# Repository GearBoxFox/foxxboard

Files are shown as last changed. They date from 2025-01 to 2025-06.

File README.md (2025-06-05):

## Foxxboard: A Wireless, split ergonomic keyboard for normal keyboard users
---
This keyboard was inspired by the Lily85 keyboard layout, keeping a more standard 64 key layout while also gaining the bonus ergonomics of a split keyboard. I designed it to be a multi purpose keyboard, ergonomic for typing while still having access to all the needed keys for competitive gaming. I also decided to build it wirelessly so I can easily take and use it with my laptop on the go.

*insert final image here*

# Features
- 64 key layout
- 4 key thumb cluster per side
- BLE wireless support using nice!nano v2
- Traditional pinky row using 1.5u keys
- Low profile using Gateron ks33 switches 
- 2x nice!view for low powered HUD
- Custom firmware written in RMK using Rust :ferrisyippee: 

## > [!NOTE]
> The firmware for the display module is still a WIP, but I'm talking with the head RMK dev 
> to get it fully running. The firmware bundled with this has parts of a display demo, and my 
> hackpad has a working display in RMK.

# PCB

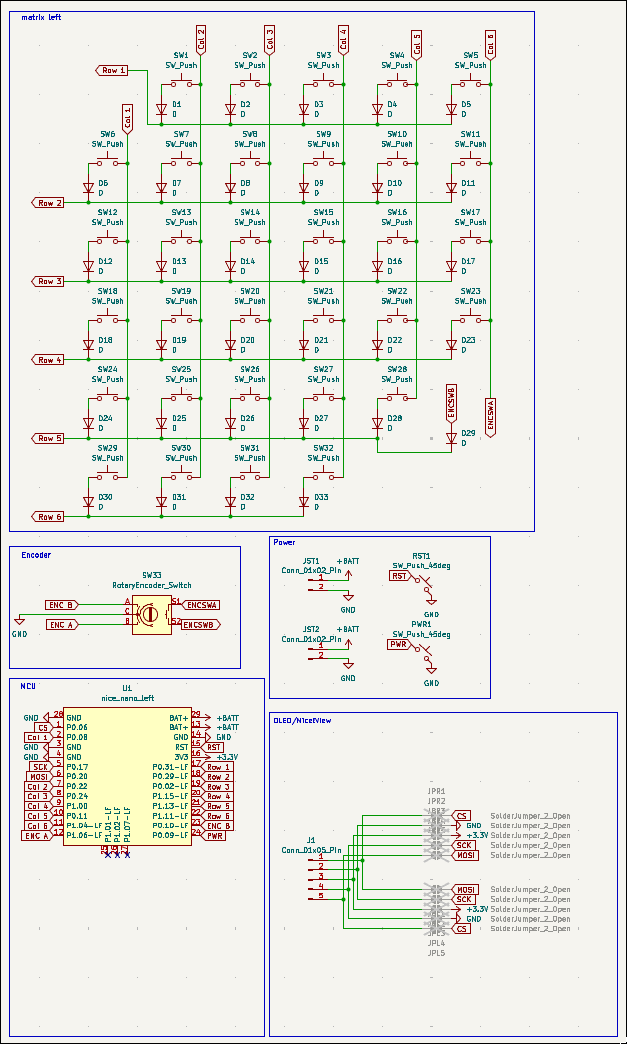
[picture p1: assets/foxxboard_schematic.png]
PCB Schematic

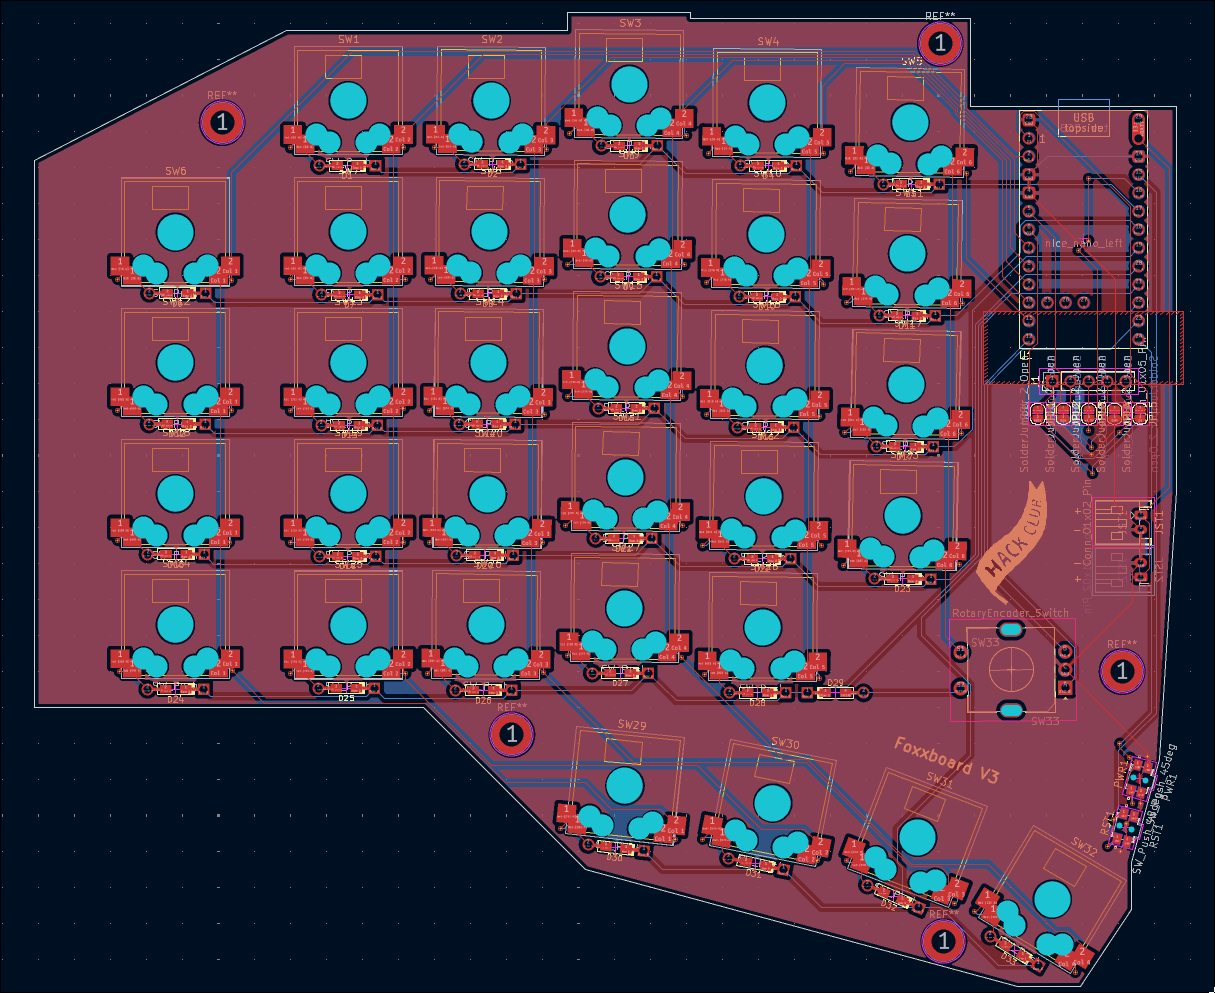
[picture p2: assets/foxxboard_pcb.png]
PCB

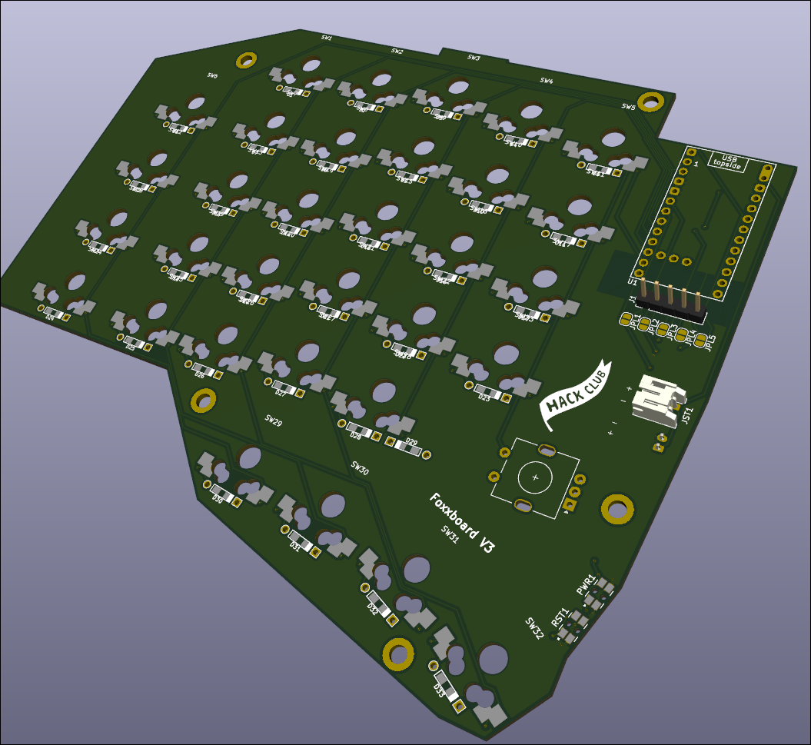
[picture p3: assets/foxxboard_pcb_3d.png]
PCB 3D


# Renders

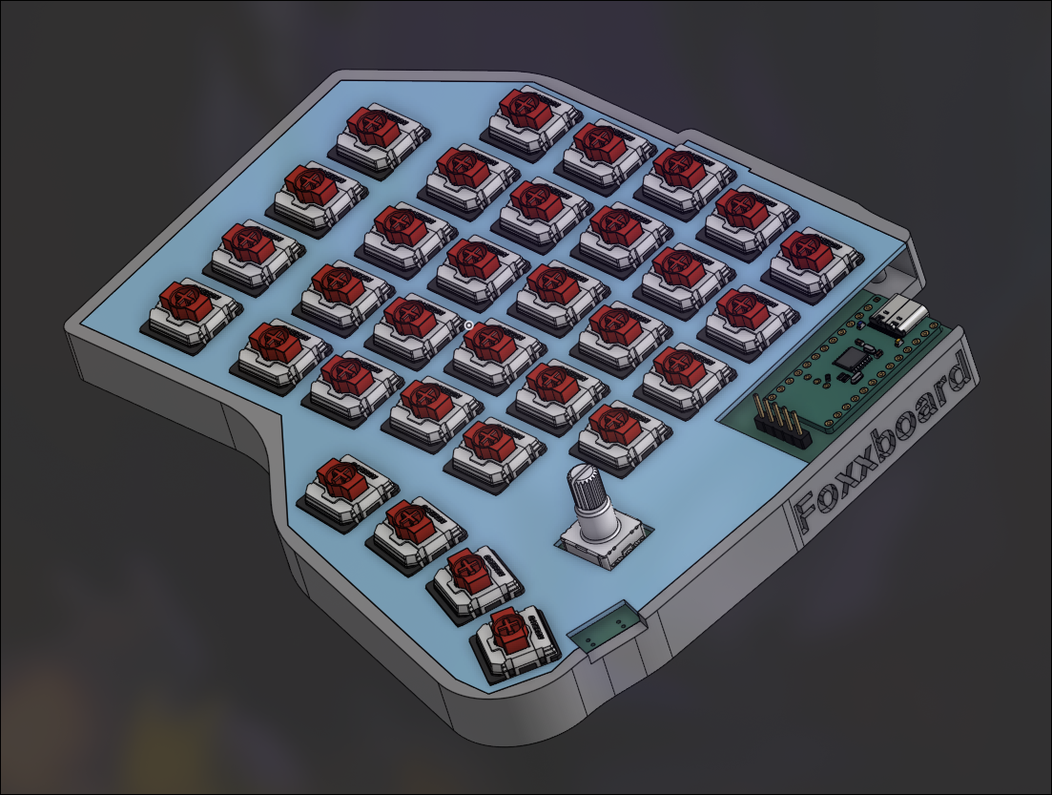
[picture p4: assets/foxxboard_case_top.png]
Top Case

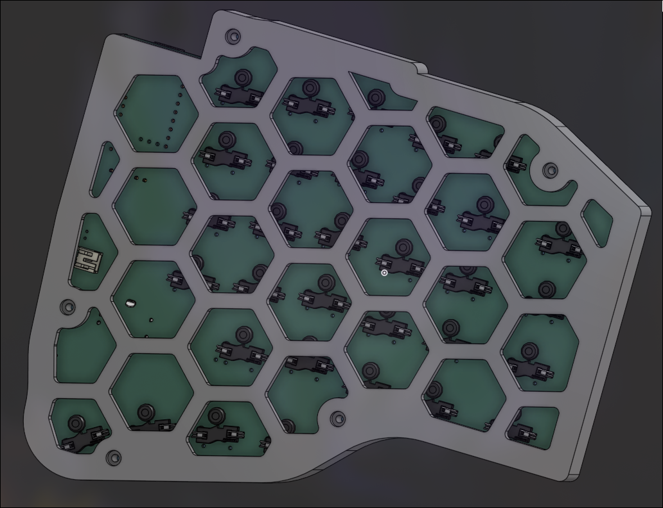
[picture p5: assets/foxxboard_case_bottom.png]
Bottom Case


# BOM 

## > [!NOTE]
> I plan on printing my own case.
>
> I also need to double check prices on things as there have almost certainly been price changes.

| Name | Qty | Price |
|---|-----|---|
| PCB | 5 | $14.59 w/shipping |
| GLP ks33 Banana | 64  | $21.48 w/shipping |
| THT 1N4148 Diodes | 64  | Hackclub |
| EC11 Encoder | 2 | $2.00 AliExpress  |
| Clone Nice!Nano V2 | 2 | $5.42 AliExpress  |
| GLP Hot-swap sockets | 100 | $8.42 AliExpress  |
| 0.91" OLED Display | 2 | $3.20 AliExpress  |
| 3.7v LiPo Battery | 2 | $6.00 |
| EVQ-P7C01P Switch | 2 | $0.56 Digikey |

| Supplier | Price (+ Shipping) | 
|---|---|
| JLCPCB | $14.59 |
| Keebio | $22.48 |
| AliExpress  | $20.20 |
| Typeractive | $10.90 |
| Total | $68.17 |

| Extras | Qty | Price |
|---|-----|---|
| Nice!View | 2 | $40 |
| True Nice!Nano V2 | 2 | $50 |

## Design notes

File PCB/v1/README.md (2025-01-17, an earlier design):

# hackpad-v2
Kicad, Ergogen, and QMK files for Hackclub's Hackpad V2

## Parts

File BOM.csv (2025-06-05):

Item | Cost | Amount | Total Cost | Link
PCB | $28.84 | 1 | $28.84 w/shipping
Gateron ks33 banana switches | $0.25 | 64 | $21.48 w/shipping | https://keeb.io/products/gateron-ks-33-low-profile-2-0-switches?variant=41274159628382
THT 1N4148 Diodes | Hackclub | 64 | HC
EC11 Encoder | self provide | 2 | self provide
Nice!Nano V2 | $25 (self provide) | 2 | $50 | https://typeractive.xyz/products/nice-nano
GLP sockets | $7.81 | 1 | $7.81 | https://www.aliexpress.us/item/3256806931242093.html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
3.7v LiPo | $4 (has to ship with nice!nano I might just buy myself as well idk) | 2 | $8 | https://typeractive.xyz/products/lithium-battery-110mah?variant=43294731665639
Total for HC | $58.13
Total for me | $58

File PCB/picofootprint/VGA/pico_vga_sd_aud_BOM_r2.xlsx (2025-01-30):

RPI-PVAS pico_vga_sd_aud BOM Rev2
17/079/2020
Reference designators | Quantity | Manufacturer Part Number (MPN) | Manufacturer | Description | Value
C1, C2 | 2 | GCM188R71C105KA64J | Murata | CAP CER 1UF 16V X7R 0603 | 1u
C9, C11 | 2 | GRM188R71A225KE15D | Murata | CAP CER 2.2UF 10V X7R 0603 | 2.2u
C3, C10, C16, C19 | 4 | GRM188R61A106KE69J | Murata | CAP CER 10UF 10V X5R 0603 | 10u
C4, C5, C6, C7, C8, C12, C13 | 7 | GRM155R71E104KE14J | Murata | CAP CER 0.1UF 25V X7R 0402 | 100n
C14, C15, C21 | 3 | GRM219R60J476ME44D | Murata | CAP CER 47UF 6.3V X5R 0805 | 47u
C17, C18 | 2 | GRM155R71H222KA01D | Murata | CAP CER 2200PF 50V X7R 0402 | 2.2n
D1 | 1 | MBR120VLSFT1G | ON Semiconductor | DIODE SCHOTTKY 20V 1A SOD123FL | MBR120VLSFT1G
J1, J2 | 2 | SJ-3523-SMT-TR | CUI Devices | CONN JACK STEREO 3.5MM SMD R/A | SJ-3523-SMT
J3 | 1 | 104031-0811 | Molex | CONN MICRO SD CARD PUSH-PULL R/A | 104031-0811
J4 | 1 | L77HDE15SD1CH4F | Amphenol ICC (Commercial Products) | CONN DSUB HD RCPT 15POS R/A SLDR | L77HDE15SD1CH4F
J5 | 1 | 10103594-0001LF | Amphenol ICC (FCI) | CONN RCPT USB2.0 MICRO B SMD R/A | 10103594-0001LF
J6 | 1 | TSW-102-23-T-S | Samtec Inc. | CONN HEADER VERT 2POS 2.54MM | TSW-102-23-T-S
J7 | 1 | 67997-208HLF | Amphenol ICC (FCI) | CONN HEADER VERT 8POS 2.54MM | 67997-208HLF
R1, R2 | 2 | RC0402FR-07220RL | Yageo | RES SMD 220 OHM 1% 1/16W 0402 | 220
R3, R4 | 2 | RC0402FR-07100RL | Yageo | RES SMD 100 OHM 1% 1/16W 0402 | 100
R5, R6 | 2 | RC0402FR-07470RP | Yageo | RES SMD 470 OHM 1% 1/16W 0402 | 470
R7, R8 | 2 | RC0402FR-071K8L | Yageo | RES SMD 1.8K OHM 1% 1/16W 0402 | 1.8K
R10, R11 | 2 | RC0402FR-0747RL | Yageo | RES SMD 47 OHM 1% 1/16W 0402 | 47
R20, R21, R22, R27, R32, R37 | 6 | RC0402FR-071KP | Yageo | RES SMD 1K OHM 1% 1/16W 0402 | 1k
R23, R24 | 2 | RC0402FR-0710KP | Yageo | RES SMD 10K OHM 1% 1/16W 0402 | 10k
R26, R31, R36 | 3 | RC0402FR-07499RL | Yageo | RES SMD 499 OHM 1% 1/16W 0402 | 499
R28, R33, R38 | 3 | RC0402FR-072KL | Yageo | RES SMD 2K OHM 1% 1/16W 0402 | 2k
R29, R34, R39 | 3 | RC0402FR-074K02L | Yageo | RES SMD 4.02K OHM 1% 1/16W 0402 | 4.02k
R30, R35, R40 | 3 | RC0402FR-078K06L | Yageo | RES SMD 8.06K OHM 1% 1/16W 0402 | 8.06k
SW1, SW2, SW3, SW4 | 4 | 434133025816 | Würth Elektronik | TACT SWITCH 4.2X3.2MM VERTICAL T | 434133025816
U1 | 1 | TLV70033DDCR | Texas Instruments | IC REG LINEAR 3.3V 200MA SOT23-5 | TLV70033DDCR
U3 | 1 | NC7WZ16P6X | ON Semiconductor | IC BUF NON-INVERT 5.5V SC70-6 | NC7WZ16P6X
U4 | 1 | PCM5101APWR | Texas Instruments | IC DAC 16/24/32BIT 384K 20TSSOP | PCM5101APWR

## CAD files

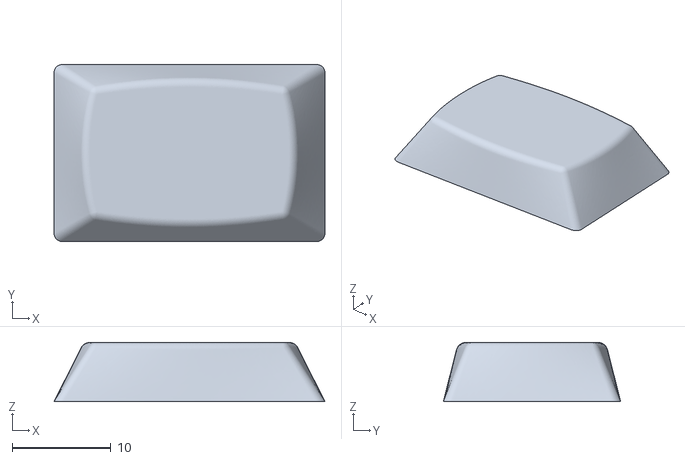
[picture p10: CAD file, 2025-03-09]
PCB/3d/AdhesionSupport_MFP_1.5u.step.stl
27.5 x 18.0 x 6.00

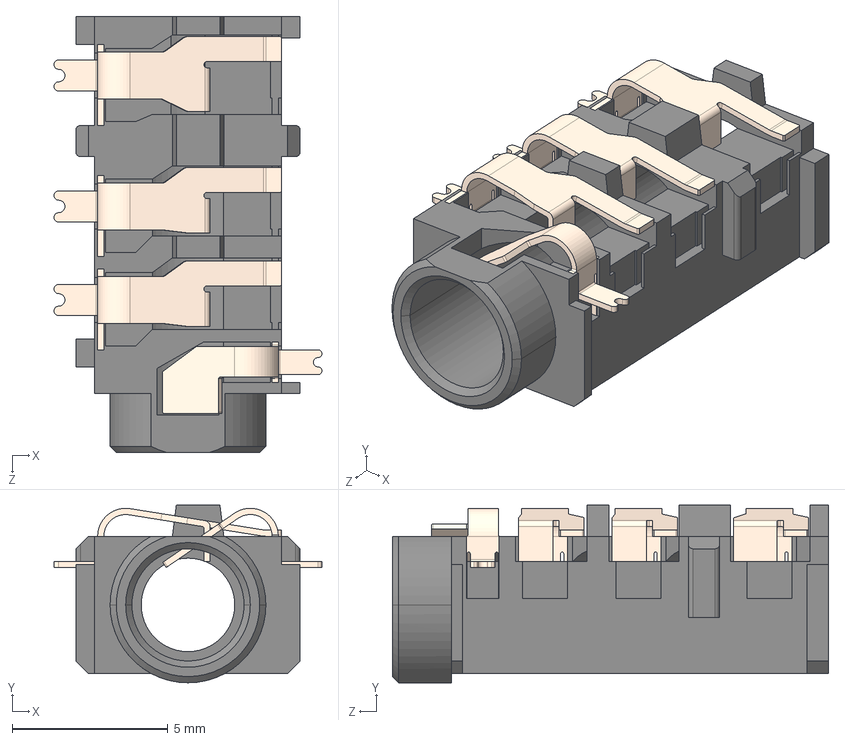
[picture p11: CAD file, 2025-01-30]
PCB/Keebio-Parts/3dmodels/CUI_SJ-43614-SMT-TR.step
8.60 x 5.70 x 14.0 mm

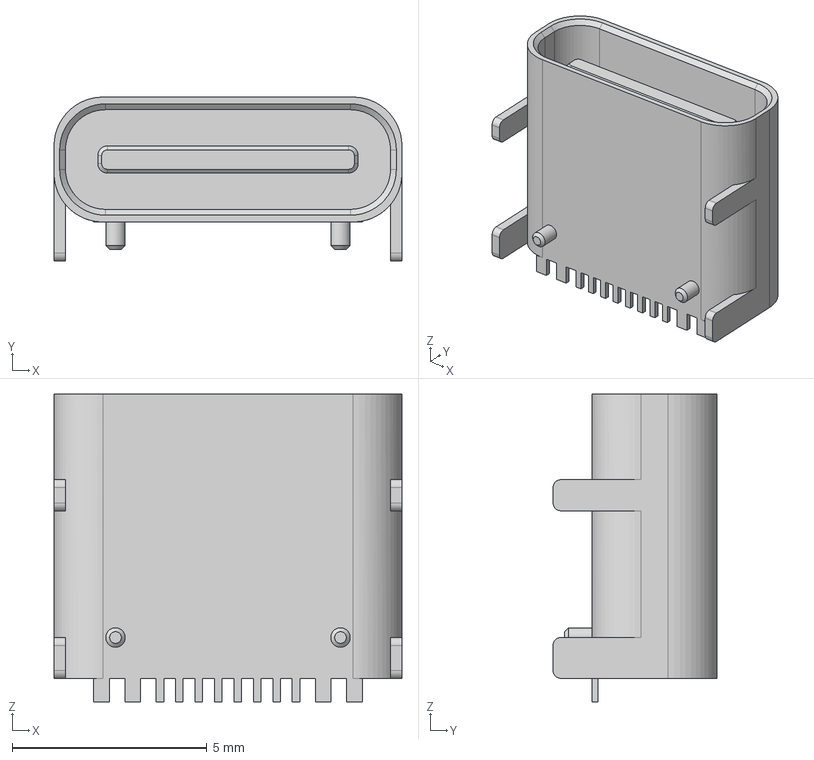
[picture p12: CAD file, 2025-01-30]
PCB/Keebio-Parts/Keebio-Parts.pretty-master/3dmodels/HRO TYPE-C-31-M-12.step
8.94 x 4.21 x 7.90 mm

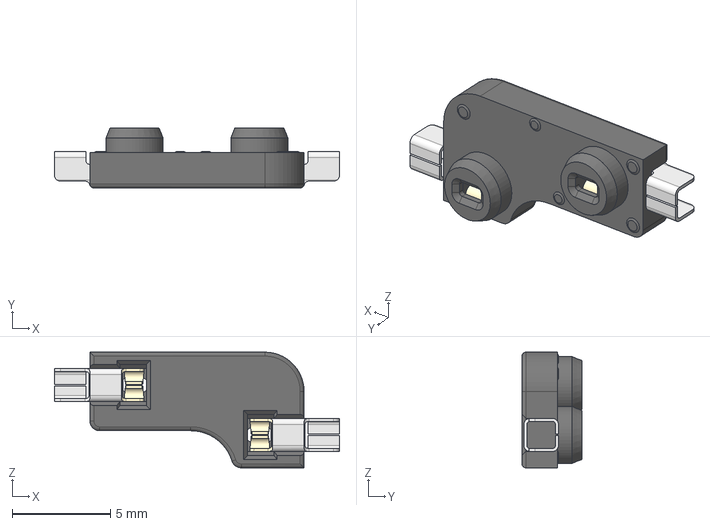
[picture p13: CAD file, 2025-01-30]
PCB/MX_V2-main/3D/MX-Hotswap-Socket.step
14.5 x 3.05 x 5.89 mm

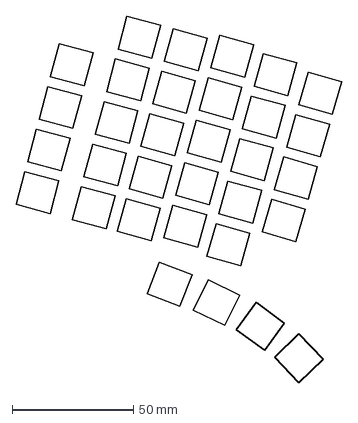
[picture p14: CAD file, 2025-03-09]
PCB/v3/switches_plate.dxf
134.3 x 151.1 mm

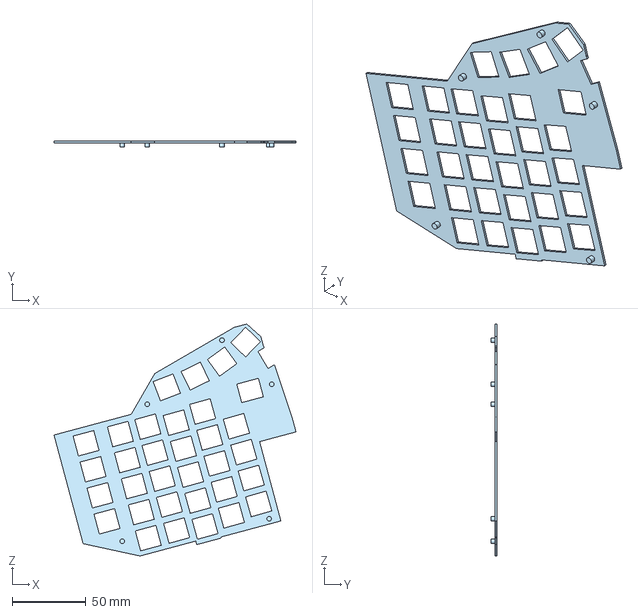
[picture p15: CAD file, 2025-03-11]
Production/Rev 3 part studio - Plate.step
163.5 x 3.90 x 156.8 mm

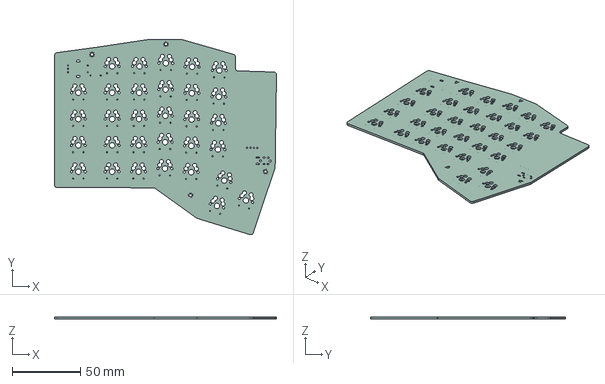
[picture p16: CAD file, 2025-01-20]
tutorial.step
162.7 x 143.3 x 1.60 mm

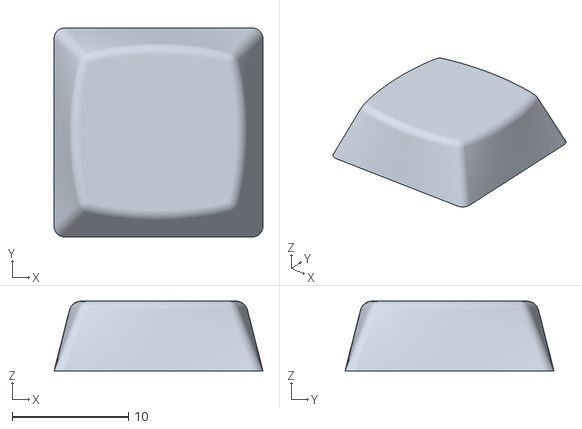
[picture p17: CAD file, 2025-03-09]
PCB/3d/AdhesionSupport_MFP_1u.step.stl
18.0 x 18.0 x 6.00

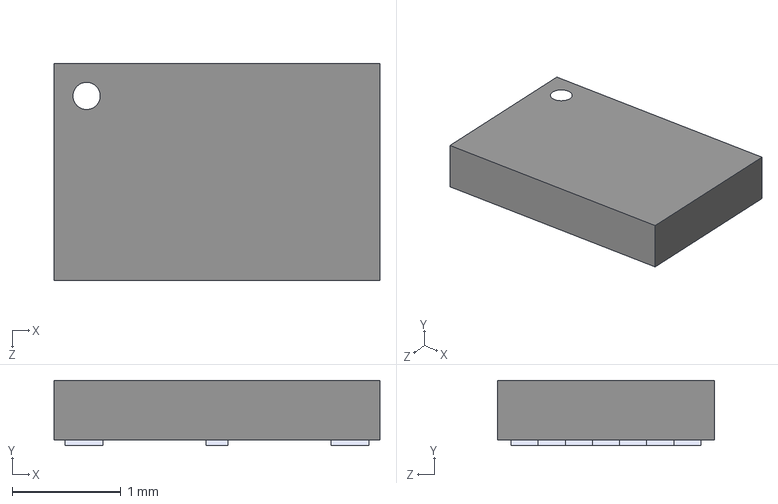
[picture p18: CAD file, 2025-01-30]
PCB/Keebio-Parts/Keebio-Parts.pretty-master/3dmodels/W25Q16JVUXIQ.step
3.00 x 0.6 x 2.00 mm

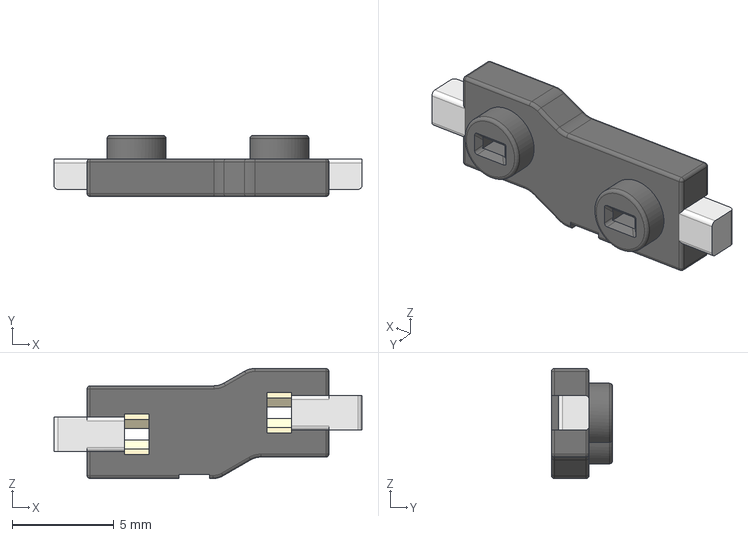
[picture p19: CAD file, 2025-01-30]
PCB/MX_V2-main/3D/Gateron-KS33-Socket.step
15.1 x 3.00 x 5.40 mm

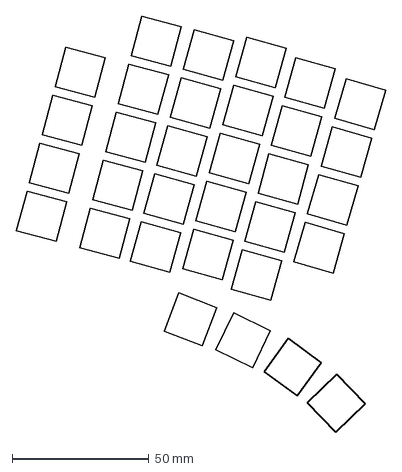
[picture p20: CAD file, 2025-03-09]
PCB/v3/switches.dxf
135.1 x 152.2 mm

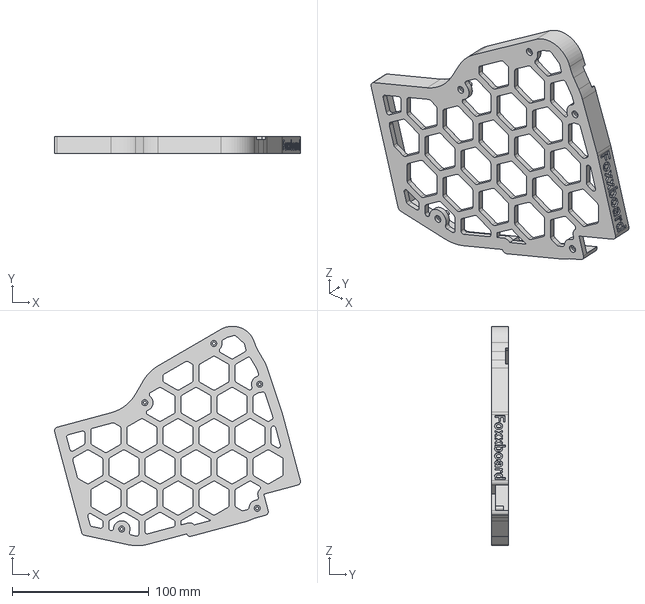
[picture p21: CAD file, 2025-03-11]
Production/Rev 3 part studio - Case.step
180.1 x 12.7 x 160.7 mm

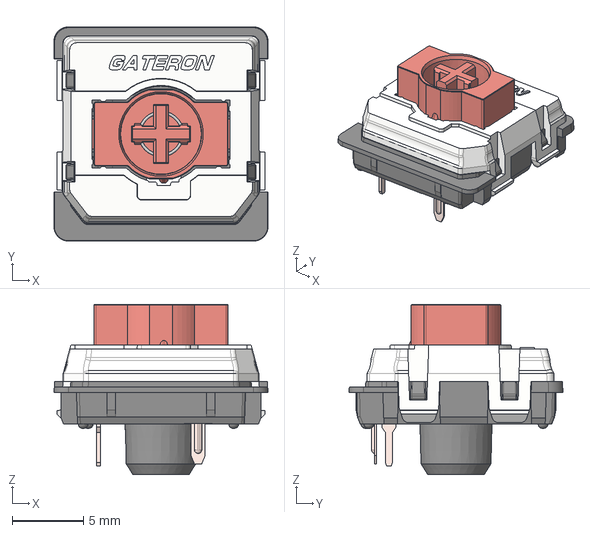
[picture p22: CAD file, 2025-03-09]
PCB/3d/KS33-low profile.step
15.0 x 15.0 x 11.9 mm

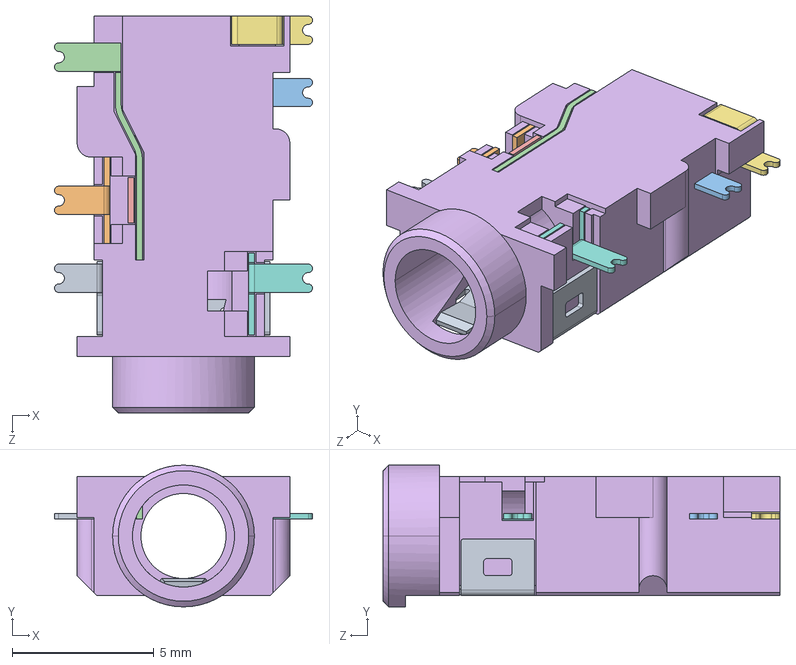
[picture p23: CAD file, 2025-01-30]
PCB/Keebio-Parts/Keebio-Parts.pretty-master/3dmodels/CUI_DEVICES_SJ-43504-SMT-TR.step
9.10 x 5.00 x 14.0 mm

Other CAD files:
PCB/MX_V2-main/3D/Kailh-Choc-Socket-CPG135001S30.step
PCB/v3/demo.dxf
PCB/3d/128x32-OLED.STEP
PCB/3d/Cherry MX.STEP
PCB/3d/EC11 Rotary Encoder Dode Switch-15mm .STEP
PCB/3d/Gateron_ks33_hotswap_socket.step
PCB/3d/[low detail] Low Profile Cherry MX Red.step
PCB/Keebio-Parts/3dmodels/EC11B-SW-Horiz-15K-blue.step
PCB/Keebio-Parts/3dmodels/PJ-320A.step
PCB/Keebio-Parts/3dmodels/SK6812MINI-E v1.step
PCB/Keebio-Parts/Keebio-Parts.pretty-master/3dmodels/EC11B-SW-Horiz-15K-blue.step
PCB/Keebio-Parts/Keebio-Parts.pretty-master/3dmodels/PJ-320A.step
PCB/Keebio-Parts/Keebio-Parts.pretty-master/3dmodels/SK6812MINI-E v1.step
PCB/v2/v2.dxf
PCB/v3/v2.dxf

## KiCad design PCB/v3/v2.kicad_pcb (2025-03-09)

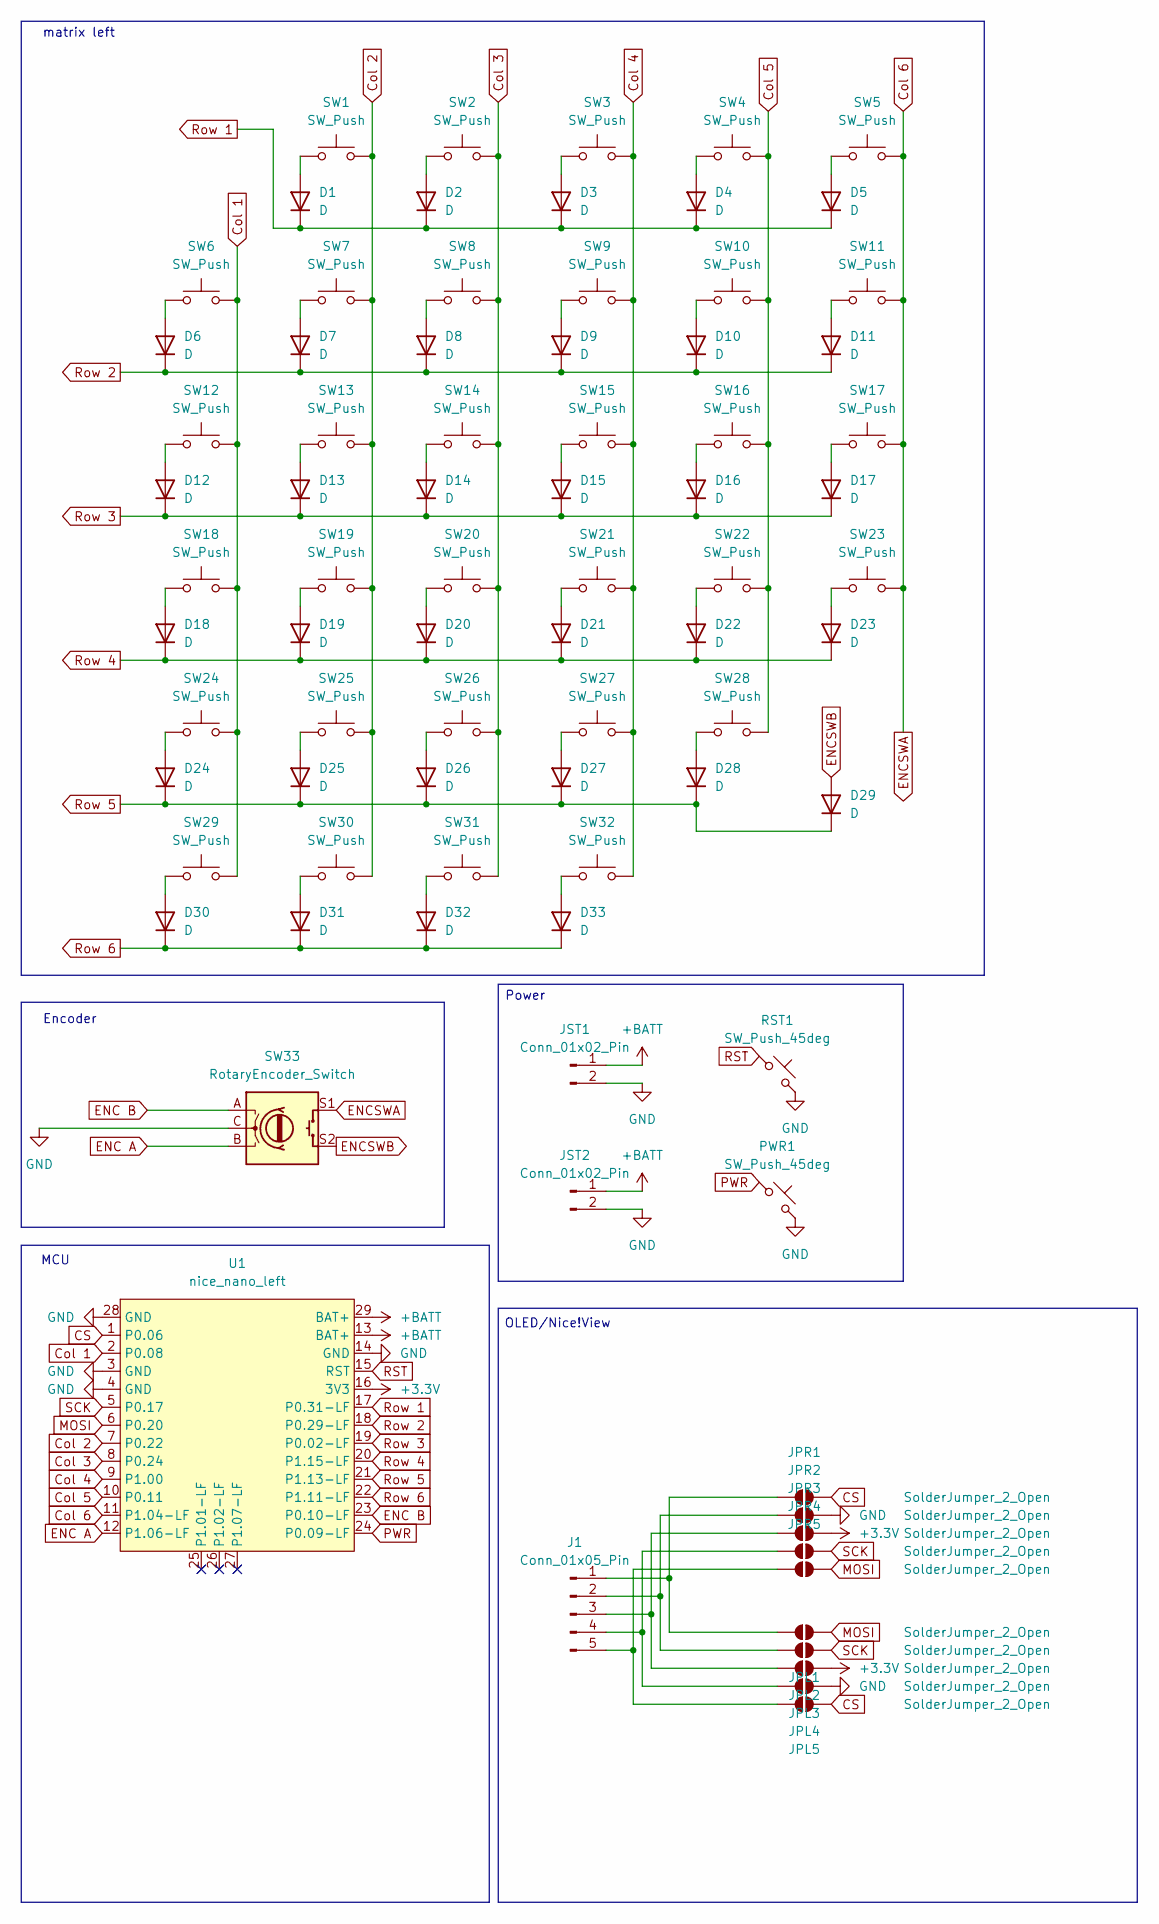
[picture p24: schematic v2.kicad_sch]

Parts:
D1, D2, D3, D4, D5, D6, D7, D8, D9, D10, D11, D12, D13, D14, D15, D16, D17, D18, D19, D20, D21, D22, D23, D24, D25, D26, D27, D28, D29, D30, D31, D32, D33: D; Diode-dual
J1: Conn_01x05_Pin; PinHeader_1x05_P2.54mm_Vertical
JPL1, JPL2, JPL3, JPL4, JPL5: SolderJumper_2_Open; SolderJumper-2_P1.3mm_Open_RoundedPad1.0x1.5mm
JPR1, JPR2, JPR3, JPR4, JPR5: SolderJumper_2_Open; SolderJumper-2_P1.3mm_Open_RoundedPad1.0x1.5mm
JST1, JST2: Conn_01x02_Pin; JST_PH_S2B-PH-K_1x02_P2.00mm_Horizontal
PWR1: SW_Push_45deg; EVQ-P7C-Reversible
RST1: SW_Push_45deg; EVQ-P7C-Reversible
SW1, SW2, SW3, SW4, SW5, SW6, SW7, SW8, SW9, SW10, SW11, SW12, SW13, SW14, SW15, SW16, SW17, SW18, SW19, SW20, SW21, SW22, SW23, SW24, SW25, SW26, SW27, SW28, SW29, SW30, SW31, SW32: SW_Push; gateron-ks27-hotswap-reversible
SW33: RotaryEncoder_Switch; RotaryEncoder_EC11
U1: nice_nano_left; nice_nano_AH_Reversible

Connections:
+3.3V: JPL3.2 (B), JPR3.2 (B), U1.16 (3V3)
+BATT: JST1.1, JST2.1, U1.13 (BAT+), U1.29 (BAT+)
CS: JPL5.2 (B), JPR1.2 (B), U1.1 (P0.06)
Col 1: SW6.2, SW12.2, SW18.2, SW24.2, SW29.2, U1.2 (P0.08)
Col 2: SW1.2, SW7.2, SW13.2, SW19.2, SW25.2, SW30.2, U1.7 (P0.22)
Col 3: SW2.2, SW8.2, SW14.2, SW20.2, SW26.2, SW31.2, U1.8 (P0.24)
Col 4: SW3.2, SW9.2, SW15.2, SW21.2, SW27.2, SW32.2, U1.9 (P1.00)
Col 5: SW4.2, SW10.2, SW16.2, SW22.2, SW28.2, U1.10 (P0.11)
Col 6: SW5.2, SW11.2, SW17.2, SW23.2, SW33.S1, U1.11 (P1.04-LF)
ENC A: SW33.B, U1.12 (P1.06-LF)
ENC B: SW33.A, U1.23 (P0.10-LF)
ENCSWB: D29.2 (A), SW33.S2
GND: JPL4.2 (B), JPR2.2 (B), JST1.2, JST2.2, PWR1.2, RST1.2, SW33.C, U1.3 (GND), U1.4 (GND), U1.14 (GND), U1.28 (GND)
MOSI: JPL1.2 (B), JPR5.2 (B), U1.6 (P0.20)
unnamed: D1.2 (A), SW1.1
unnamed: D2.2 (A), SW2.1
unnamed: D3.2 (A), SW3.1
unnamed: D4.2 (A), SW4.1
unnamed: D5.2 (A), SW5.1
unnamed: D6.2 (A), SW6.1
unnamed: D7.2 (A), SW7.1
unnamed: D8.2 (A), SW8.1
unnamed: D9.2 (A), SW9.1
unnamed: D10.2 (A), SW10.1
unnamed: D11.2 (A), SW11.1
unnamed: D12.2 (A), SW12.1
unnamed: D13.2 (A), SW13.1
unnamed: D14.2 (A), SW14.1
unnamed: D15.2 (A), SW15.1
unnamed: D16.2 (A), SW16.1
unnamed: D17.2 (A), SW17.1
unnamed: D18.2 (A), SW18.1
unnamed: D19.2 (A), SW19.1
unnamed: D20.2 (A), SW20.1
unnamed: D21.2 (A), SW21.1
unnamed: D22.2 (A), SW22.1
unnamed: D23.2 (A), SW23.1
unnamed: D24.2 (A), SW24.1
unnamed: D25.2 (A), SW25.1
unnamed: D26.2 (A), SW26.1
unnamed: D27.2 (A), SW27.1
unnamed: D28.2 (A), SW28.1
unnamed: D30.2 (A), SW29.1
unnamed: D31.2 (A), SW30.1
unnamed: D32.2 (A), SW31.1
unnamed: D33.2 (A), SW32.1
unnamed: J1.1, JPL1.1 (A), JPR1.1 (A)
unnamed: J1.2, JPL2.1 (A), JPR2.1 (A)
unnamed: J1.3, JPL3.1 (A), JPR3.1 (A)
unnamed: J1.4, JPL4.1 (A), JPR4.1 (A)
unnamed: J1.5, JPL5.1 (A), JPR5.1 (A)
PWR: PWR1.1, U1.24 (P0.09-LF)
RST: RST1.1, U1.15 (RST)
Row 1: D1.1 (K), D2.1 (K), D3.1 (K), D4.1 (K), D5.1 (K), U1.17 (P0.31-LF)
Row 2: D6.1 (K), D7.1 (K), D8.1 (K), D9.1 (K), D10.1 (K), D11.1 (K), U1.18 (P0.29-LF)
Row 3: D12.1 (K), D13.1 (K), D14.1 (K), D15.1 (K), D16.1 (K), D17.1 (K), U1.19 (P0.02-LF)
Row 4: D18.1 (K), D19.1 (K), D20.1 (K), D21.1 (K), D22.1 (K), D23.1 (K), U1.20 (P1.15-LF)
Row 5: D24.1 (K), D25.1 (K), D26.1 (K), D27.1 (K), D28.1 (K), D29.1 (K), U1.21 (P1.13-LF)
Row 6: D30.1 (K), D31.1 (K), D32.1 (K), D33.1 (K), U1.22 (P1.11-LF)
SCK: JPL2.2 (B), JPR4.2 (B), U1.5 (P0.17)

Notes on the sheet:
MCU
Encoder
matrix left
Power
OLED/Nice!View

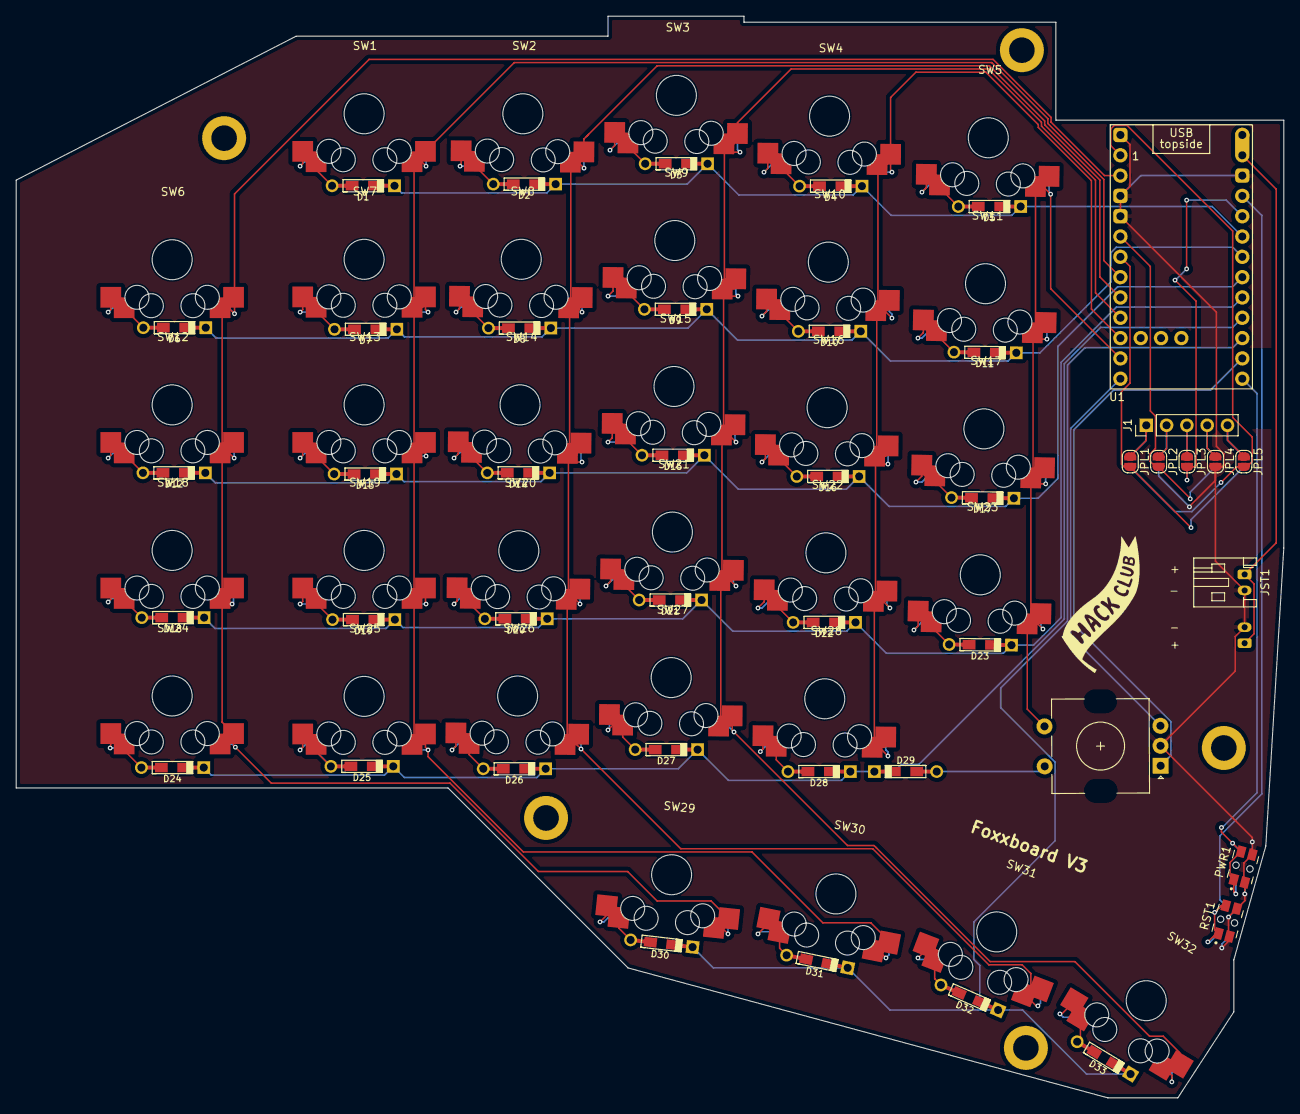
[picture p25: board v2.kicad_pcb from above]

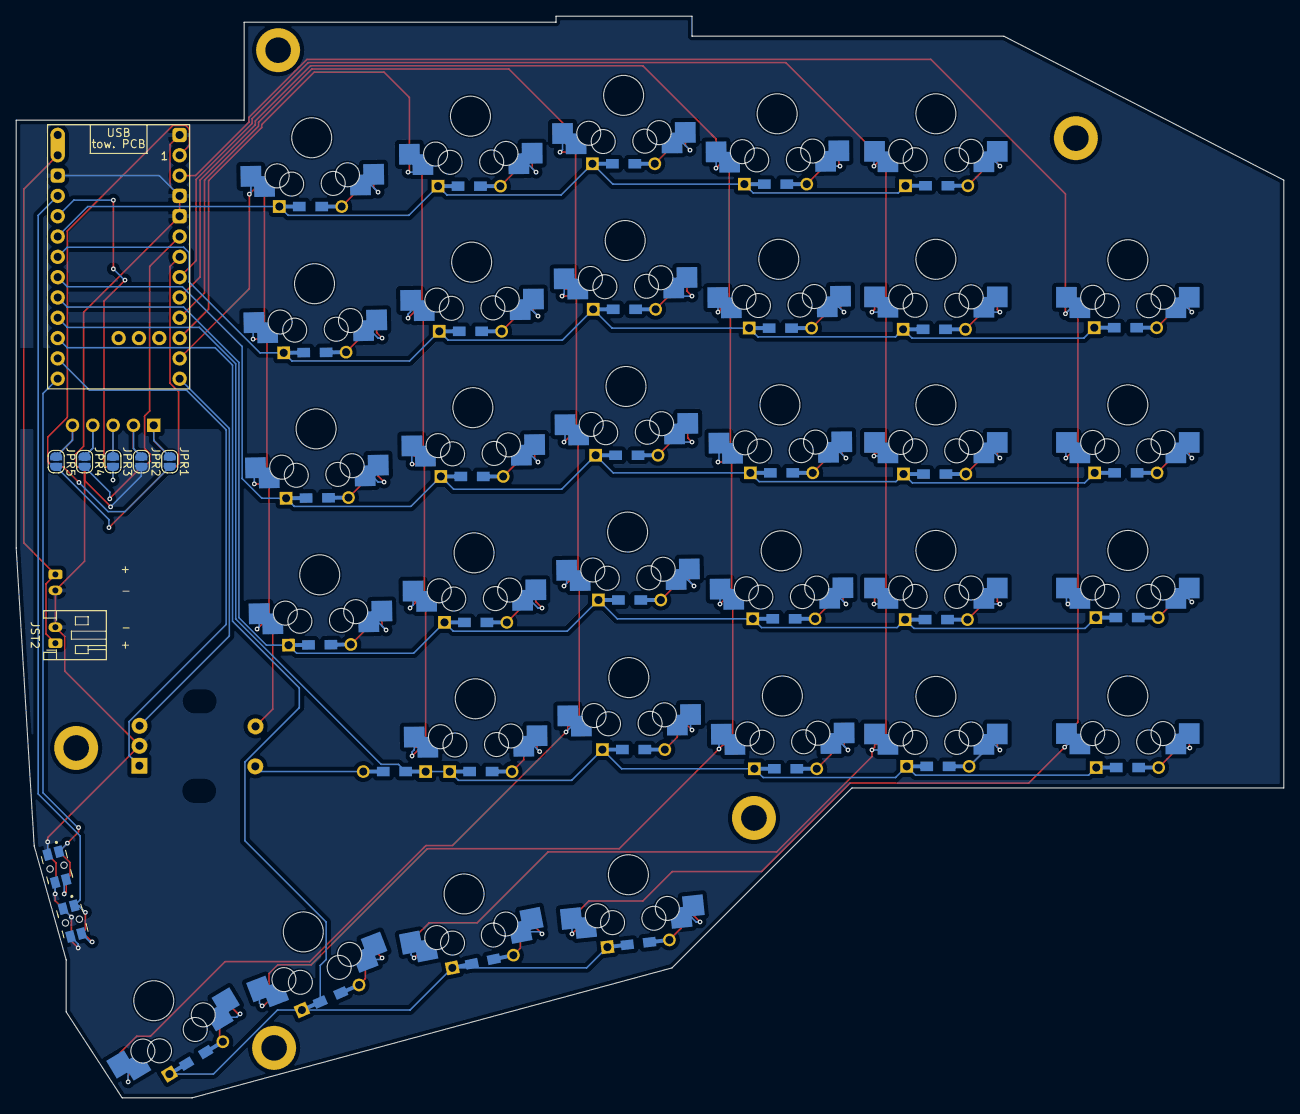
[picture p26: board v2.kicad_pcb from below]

Board: 2 copper layers, 158.5 x 135.2 mm, 82 parts (6 on the bottom side), 60 nets.

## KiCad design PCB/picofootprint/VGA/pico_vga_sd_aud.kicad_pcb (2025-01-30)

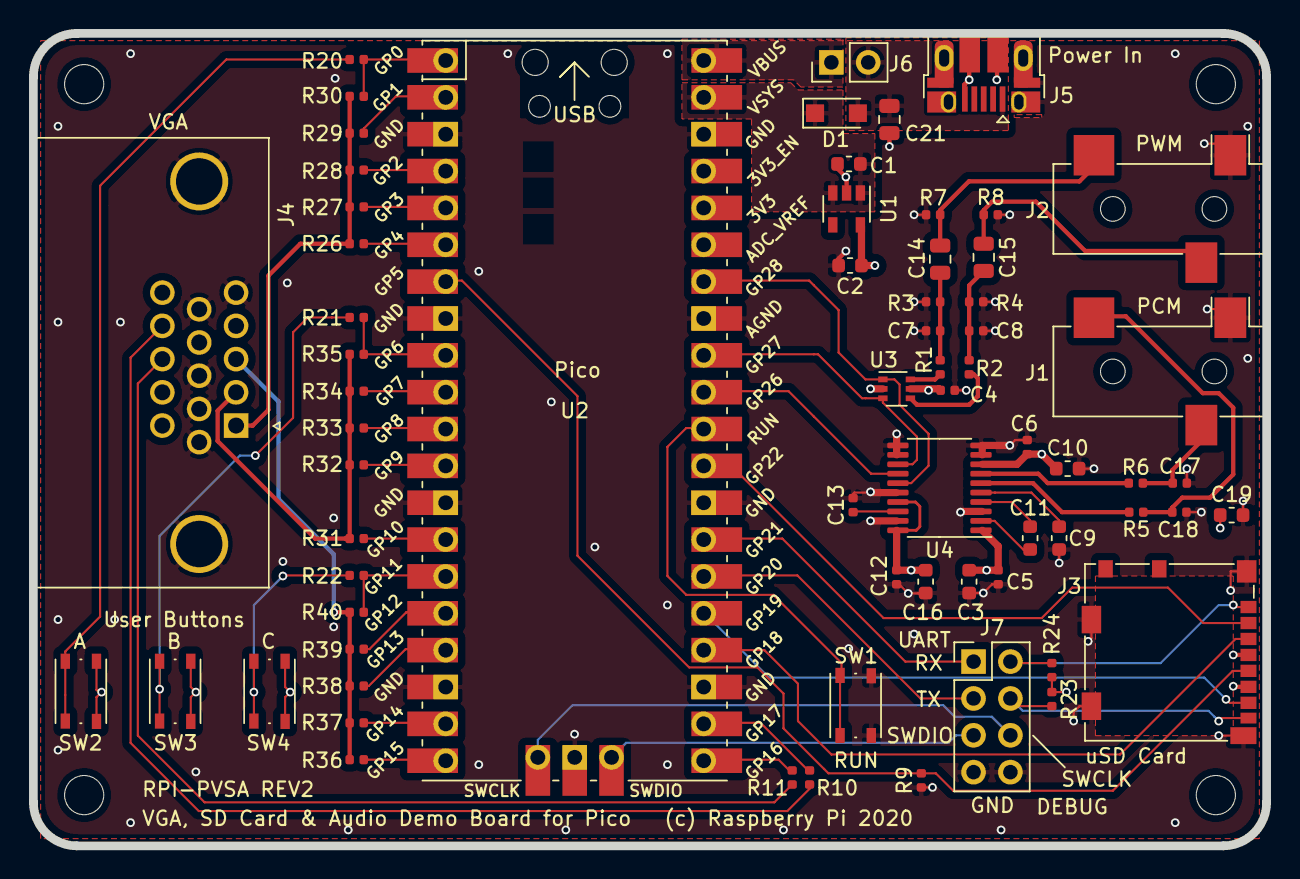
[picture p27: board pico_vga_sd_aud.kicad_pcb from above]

Board: 4 copper layers, 85.0 x 56.0 mm, 71 parts (0 on the bottom side), 59 nets.

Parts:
C1, C2: 1u; C_0603_1608Metric
C3, C10, C16, C19: 10u; C_0603_1608Metric
C4, C5, C6, C7, C8, C12, C13: 100n; C_0402_1005Metric
C9, C11: 2.2u; C_0603_1608Metric
C14, C15, C21: 47u; C_0805_2012Metric
C17, C18: 2.2n; C_0402_1005Metric
D1: MBR120; MBR120_SOD-123
H1, H2, H3, H4: MountingHole; MountingHole_2.7mm_M2.5
J1, J2: AudioJack3; CUI_SJ-3523-audio-jack
J3: Micro_SD_Card; microSD_HC_Molex_104031-0811
J4: L77HDE15SD1CH4F; DSUB-15-L77HDE15SD1CH4F
J5: USB_B_Micro; USB_Micro-B_Amphenol_10103594-0001LF_Horizontal_modified
J6: Conn_01x02; PinHeader_1x02_P2.54mm_Vertical
J7: Conn_02x03_Odd_Even; PinHeader_2x04_P2.54mm_Vertical
R1, R2: 220; R_0402_1005Metric
R3, R4: 100; R_0402_1005Metric
R5, R6: 470; R_0402_1005Metric
R7, R8: 1.8K; R_0402_1005Metric
R9: DNF; R_0402_1005Metric
R10, R11: 47; R_0402_1005Metric
R20, R21, R22, R27, R32, R37: 1k; R_0402_1005Metric
R23, R24: 10k; R_0402_1005Metric
R26, R31, R36: 499; R_0402_1005Metric
R28, R33, R38: 2k; R_0402_1005Metric
R29, R34, R39: 4.02k; R_0402_1005Metric
R30, R35, R40: 8.06k; R_0402_1005Metric
SW1, SW2, SW3, SW4: SW_Push; SW_Push_1P1T_NO_Vertical_Wuerth_434133025816
U1: TLV70033_SOT23-5; SOT-23-5
U2: Pico; RPi_Pico_SMD_TH
U3: NC7WZ16P6X; SOT-363_SC-70-6
U4: PCM5101A; TSSOP-20_4.4x6.5mm_P0.65mm

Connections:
+3.3VA: C2.1, C3.1, C4.1, C5.1, C6.1, C10.1, U1.5, U3.5, U4.1, U4.8
+3V3: C12.1, C16.1, C19.1, J3.4, R23.2, R24.2, SW2.1, SW3.1, SW4.1, U2.36, U4.17, U4.20
+5V: C21.2, D1.2, J5.1, J6.2
/GPIO0: R20.1, R30.2, U2.1
/GPIO1: R29.2, U2.2
/GPIO2: R28.2, U2.4
/GPIO3: R27.2, U2.5
/GPIO4: R26.2, U2.6
/GPIO5: J3.5, R9.2, U2.7
/GPIO6: R21.1, R35.2, U2.9
/GPIO7: R34.2, U2.10
/GPIO8: R33.2, U2.11
/GPIO9: R32.2, U2.12
/GPIO10: R31.2, U2.14
/GPIO11: R22.1, R40.2, U2.15
/GPIO12: R39.2, U2.16
/GPIO13: R38.2, U2.17
/GPIO14: R37.2, U2.19
/GPIO15: R36.2, U2.20
/GPIO16: R11.2, U2.21
/GPIO17: R10.2, U2.22
/GPIO18: J3.3, U2.24
/GPIO19: J3.7, U2.25
/GPIO20: J7.3, U2.26
/GPIO21: J7.1, U2.27
/GPIO22: J3.2, U2.29
/GPIO26: U2.31, U4.14
/GPIO27: U2.32, U3.3, U4.13
/GPIO28: U2.34, U3.1, U4.15
/HSYNC: J4.13, R11.1
/PCM_AUDIO_L: C18.1, J1.2, R5.1
/PCM_AUDIO_R: C17.1, J1.3, R6.1
/PCM_L: R5.2, U4.6
/PCM_R: R6.2, U4.7
/PWM_AUDIO_L: C14.1, J2.2, R7.2
/PWM_AUDIO_R: C15.1, J2.3, R8.2
/PWM_L: R1.2, U3.6
/PWM_LL: C7.1, C14.2, R1.1, R3.2
/PWM_R: R2.2, U3.4
/PWM_RR: C8.1, C15.2, R2.1, R4.2
/RUN: SW1.1, U2.30
/SD_DAT1: J3.8, J7.4, R24.1
/SD_DAT2: J3.1, J7.2, R23.1
/SWCLK: J7.6, U2.41
/SWDIO: J7.5, U2.43
/VGA_B: J4.3, R36.1, R37.1, R38.1, R39.1, R40.1
/VGA_G: J4.2, R31.1, R32.1, R33.1, R34.1, R35.1
/VGA_R: J4.1, R26.1, R27.1, R28.1, R29.1, R30.1
/VSYNC: J4.14, R10.1
/VSYS: C1.1, D1.1, U1.1, U1.3, U2.39
GND: C1.2, C2.2, C3.2, C4.2, C5.2, C6.2, C7.2, C8.2, C9.2, C10.2, C12.2, C13.2, C16.2, C17.2, C18.2, C19.2, C21.1, J1.1, J2.1, J3.6, J3.11, J4.0, J4.5, J4.6, J4.7, J4.8, J4.10, J5.5, J5.6, J7.7, J7.8, R3.1, R4.1, R7.1, R8.1, R9.1, SW1.2, U1.2, U2.3, U2.8, U2.13, U2.18, U2.23, U2.28, U2.33, U2.38, U2.42, U3.2, U4.3, U4.9, U4.10, U4.11, U4.12, U4.16, U4.19
unnamed: C9.1, U4.5
unnamed: C11.1, U4.2
unnamed: C11.2, U4.4
unnamed: C13.1, U4.18
unnamed: R20.2, SW2.2
unnamed: R21.2, SW3.2
unnamed: R22.2, SW4.2
VBUS: J6.1, U2.40

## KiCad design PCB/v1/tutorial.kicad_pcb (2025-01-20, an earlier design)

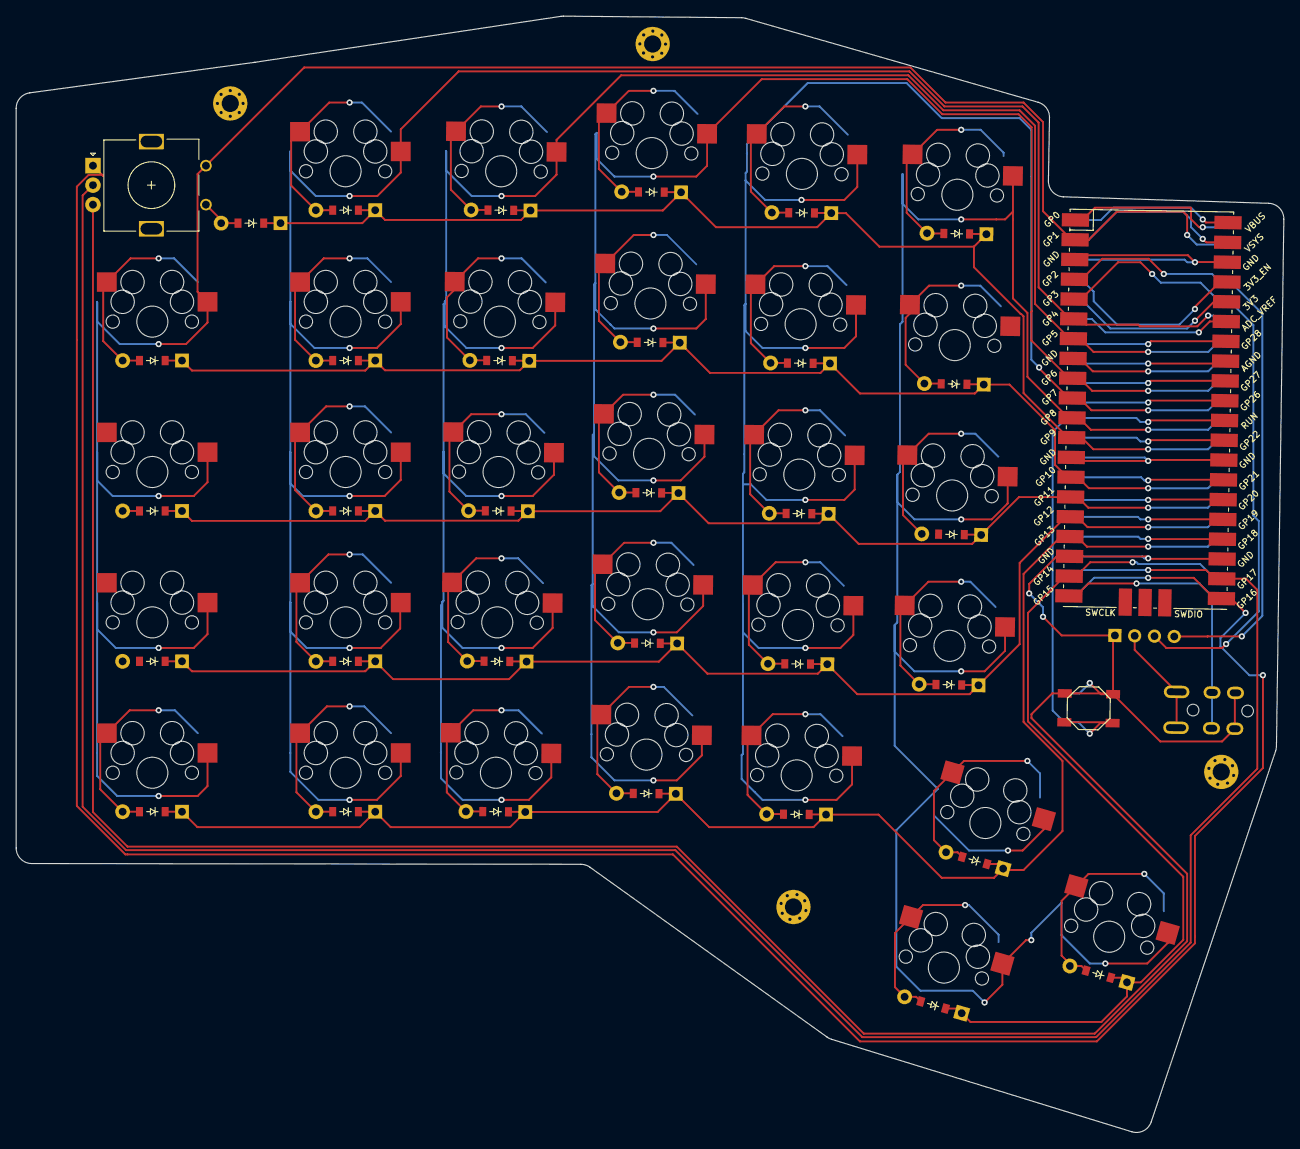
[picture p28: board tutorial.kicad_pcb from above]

Board: 2 copper layers, 162.7 x 143.3 mm, 74 parts (0 on the bottom side), 67 nets.

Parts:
B1, B2: SW_TACT_ALPS_SKQGABE010
D1, D2, D3, D4, D4#2, D5, D6, D7, D8, D9, D10, D11, D12, D13, D14, D15, D16, D17, D18, D19, D20, D21, D22, D23, D24, D25, D26, D27, D28, D29, D30, D31: ComboDiode
OLED1: OLED; OLED_headers
ROT1: rotary_encoder
S1, S2, S3, S4, S5, S6, S7, S8, S9, S10, S11, S12, S13, S14, S15, S16, S17, S18, S19, S20, S21, S22, S23, S24, S25, S26, S27, S28, S29, S30, S31: MX
TRRS1: trrs_pj320a (reversible, symmetric)
_1, _1#2: RPi_Pico_SMD_TH
_2, _3, _4, _5: MountingHole_2.2mm_M2_Pad_Via

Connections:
3V3: _1.36, _1#2.36
3V3_EN: _1.37, _1#2.37
ADC_VREF: _1.35, _1#2.35
AGND: _1.33, _1#2.33
GND: B1.1, B2.1, OLED1.1, ROT1.B, TRRS1.2, _1.3, _1.8, _1.13, _1.18, _1.23, _1.28, _1.38, _1#2.3, _1#2.8, _1#2.13, _1#2.18, _1#2.23, _1#2.28, _1#2.38
GP0: _1.1, _1#2.1
GP1: ROT1.1, S1.1, S2.1, S3.1, S4.1, _1.2, _1#2.2
GP2: OLED1.4, _1.4, _1#2.4
GP3: OLED1.3, _1.5, _1#2.5
GP4: S5.1, S6.1, S7.1, S8.1, S9.1, _1.6, _1#2.6
GP5: S10.1, S11.1, S12.1, S13.1, S14.1, _1.7, _1#2.7
GP6: S15.1, S16.1, S17.1, S18.1, S19.1, _1.9, _1#2.9
GP7: S20.1, S21.1, S22.1, S23.1, S24.1, _1.10, _1#2.10
GP8: S25.1, S26.1, S27.1, S28.1, S29.1, S30.1, S31.1, _1.11, _1#2.11
GP9: D4.1, D9.1, D14.1, D19.1, D24.1, D28.1, _1.12, _1#2.12
GP10: D4#2.1, D8.1, D13.1, D18.1, D23.1, D27.1, _1.14, _1#2.14
GP11: D3.1, D7.1, D12.1, D17.1, D22.1, D26.1, _1.15, _1#2.15
GP12: D2.1, D6.1, D11.1, D16.1, D21.1, D25.1, _1.16, _1#2.16
GP13: D1.1, D5.1, D10.1, D15.1, D20.1, D30.1, _1.17, _1#2.17
GP14: D29.1, D31.1, _1.19, _1#2.19
GP15: TRRS1.3, _1.20, _1#2.20
GP16: ROT1.A, _1.21, _1#2.21
GP17: ROT1.C, _1.22, _1#2.22
GP18: _1.24, _1#2.24
GP19: _1.25, _1#2.25
GP20: _1.26, _1#2.26
GP21: _1.27, _1#2.27
GP22: _1.29, _1#2.29
GP26: _1.31, _1#2.31
GP27: _1.32, _1#2.32
GP28: _1.34, _1#2.34
RUN: B1.2, B2.2, _1.30, _1#2.30
VBUS: _1.40, _1#2.40
VCC: OLED1.2, TRRS1.4
VSYS: _1.39, _1#2.39
enc: D4.2, ROT1.2
index_bottom: D21.2, S21.2
index_home: D22.2, S22.2
index_mod: D20.2, S20.2
index_num: D24.2, S24.2
index_top: D23.2, S23.2
inner_bottom: D25.2, S25.2
inner_home: D26.2, S26.2
inner_num: D28.2, S28.2
inner_top: D27.2, S27.2
layer_cluster: D29.2, S29.2
layer_top: D30.2, S30.2
middle_bottom: D16.2, S16.2
middle_home: D17.2, S17.2
middle_mod: D15.2, S15.2
middle_num: D19.2, S19.2
middle_top: D18.2, S18.2
outer_bottom: D1.2, S1.2
outer_home: D2.2, S2.2
outer_num: D4#2.2, S4.2
outer_top: D3.2, S3.2
pinky_bottom: D6.2, S6.2
pinky_home: D7.2, S7.2
pinky_mod: D5.2, S5.2
pinky_num: D9.2, S9.2
pinky_top: D8.2, S8.2
ring_bottom: D11.2, S11.2
ring_home: D12.2, S12.2
ring_mod: D10.2, S10.2
ring_num: D14.2, S14.2
ring_top: D13.2, S13.2
space_cluster: D31.2, S31.2

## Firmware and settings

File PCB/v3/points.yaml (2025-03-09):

matrix_outer_bottom:
  x: 110.7765238
  'y': -166.1318807
  r: -15
  meta:
    stagger: 0
    spread: 18.2
    splay: 0
    origin:
      - 0
      - 0
    orient: 0
    shift:
      - 0
      - 0
    rotate: 0
    width: 27.299999999999997
    height: 18.5
    padding: 18.2
    autobind: 10
    skip: false
    asym: both
    colrow: outer_bottom
    name: matrix_outer_bottom
    zone: &ref_1
      key:
        padding: 1kc
        spread: 1kc
      columns:
        outer: &ref_0
          rows:
            mod:
              skip: true
          key:
            width: 1.5kc
          name: outer
        pinky: &ref_2
          key:
            stagger: 1kc
            spread: 1.25kp
          rows: {}
          name: pinky
        ring: &ref_3
          key:
            splay: -0.5
            spread: kp
          rows: {}
          name: ring
        middle: &ref_4
          key:
            stagger: 2.5
            spread: kp
          rows: {}
          name: middle
        index: &ref_5
          key:
            stagger: -2.5
            spread: kp
          rows: {}
          name: index
        inner: &ref_6
          rows:
            mod:
              skip: true
          key:
            stagger: -2.5
            splay: -0.5
            spread: kp
          name: inner
      rows:
        mod: {}
        bottom: {}
        home: {}
        top: {}
        num: {}
      name: matrix
    col: *ref_0
    row: bottom
    bind:
      - 10
      - 10
      - 10
      - 0
matrix_outer_home:
  x: 115.4870304
  'y': -148.5520306
  r: -15
  meta:
    stagger: 0
    spread: 18.2
    splay: 0
    origin:
      - 0
      - 0
    orient: 0
    shift:
      - 0
      - 0
    rotate: 0
    width: 27.299999999999997
    height: 18.5
    padding: 18.2
    autobind: 10
    skip: false
    asym: both
    colrow: outer_home
    name: matrix_outer_home
    zone: *ref_1
    col: *ref_0
    row: home
    bind:
      - 10
      - 10
      - 10
      - 0
matrix_outer_top:
  x: 120.197537
  'y': -130.9721806
  r: -15
  meta:
    stagger: 0
    spread: 18.2
    splay: 0
    origin:
      - 0
      - 0
    orient: 0
    shift:
      - 0
      - 0
    rotate: 0
    width: 27.299999999999997
    height: 18.5
    padding: 18.2
    autobind: 10
    skip: false
    asym: both
    colrow: outer_top
    name: matrix_outer_top
    zone: *ref_1
    col: *ref_0
    row: top
    bind:
      - 10
      - 10
      - 10
      - 0
matrix_outer_num:
  x: 124.9080437
  'y': -113.3923306
  r: -15
  meta:
    stagger: 0
    spread: 18.2
    splay: 0
    origin:
      - 0
      - 0
    orient: 0
    shift:
      - 0
      - 0
    rotate: 0
    width: 27.299999999999997
    height: 18.5
    padding: 18.2
    autobind: 10
    skip: false
    asym: both
    colrow: outer_num
    name: matrix_outer_num
    zone: *ref_1
    col: *ref_0
    row: num
    bind:
      - 0
      - 10
      - 10
      - 0
matrix_pinky_mod:
  x: 133.9587436
  'y': -172.3435378
  r: -15
  meta:
    stagger: 18.2
    spread: 24
    splay: 0
    origin:
      - 0
      - 0
    orient: 0
    shift:
      - 0
      - 0
    rotate: 0
    width: 18.5
    height: 18.5
    padding: 18.2
    autobind: 10
    skip: false
    asym: both
    colrow: pinky_mod
    name: matrix_pinky_mod
    zone: *ref_1
    col: *ref_2
    row: mod
    bind:
      - 10
      - 10
      - 0
      - 10
matrix_pinky_bottom:
  x: 138.6692503
  'y': -154.7636877
  r: -15
  meta:
    stagger: 18.2
    spread: 24
    splay: 0
    origin:
      - 0
      - 0
    orient: 0
    shift:
      - 0
      - 0
    rotate: 0
    width: 18.5
    height: 18.5
    padding: 18.2
    autobind: 10
    skip: false
    asym: both
    colrow: pinky_bottom
    name: matrix_pinky_bottom
    zone: *ref_1
    col: *ref_2
    row: bottom
    bind:
      - 10
      - 10
      - 10
      - 10
matrix_pinky_home:
  x: 143.3797569
  'y': -137.1838377
  r: -15
  meta:
    stagger: 18.2
    spread: 24
    splay: 0
    origin:
      - 0
      - 0
    orient: 0
    shift:
      - 0
      - 0
    rotate: 0
    width: 18.5
    height: 18.5
    padding: 18.2
    autobind: 10
    skip: false
    asym: both
    colrow: pinky_home
    name: matrix_pinky_home
    zone: *ref_1
    col: *ref_2
    row: home
    bind:
      - 10
      - 10
      - 10
      - 10
matrix_pinky_top:
  x: 148.0902635
  'y': -119.6039876
  r: -15
  meta:
    stagger: 18.2
    spread: 24
    splay: 0
    origin:
      - 0
      - 0
    orient: 0
    shift:
      - 0
      - 0
    rotate: 0
    width: 18.5
    height: 18.5
    padding: 18.2
    autobind: 10
    skip: false
    asym: both
    colrow: pinky_top
    name: matrix_pinky_top
    zone: *ref_1
    col: *ref_2
    row: top
    bind:
      - 10
      - 10
      - 10
      - 10
matrix_pinky_num:
  x: 152.8007701
  'y': -102.0241376
  r: -15
  meta:
    stagger: 18.2
    spread: 24
    splay: 0
    origin:
      - 0
      - 0
    orient: 0
    shift:
      - 0
      - 0
    rotate: 0
    width: 18.5
    height: 18.5
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

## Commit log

2025-01-17 add project files
    [splitboard.kicad_pcb, splitboard.kicad_sch, tutorial.kicad_pcb]
2025-01-17 added pico, moved parts around
2025-01-19 modified the pcb some
    [tutorial.kicad_pcb]
2025-01-19 fixed positioning for pico and trrs, added oled
    [tutorial.kicad_pcb]
2025-01-19 add reset buttons
    [tutorial.kicad_pcb]
2025-01-19 define pins
    [tutorial.kicad_pcb]
2025-01-20 ready to start routing
    [tutorial.kicad_pcb]
2025-01-20 attempt to set up routing
    [tutorial.kicad_pcb]
2025-01-20 routing setup done, now to actually route
    [tutorial.kicad_pcb]
2025-01-20 fix routing setup
    [tutorial.kicad_pcb]
2025-01-20 routing done!
    [tutorial.kicad_pcb]
2025-01-20 added an diode for the encoder
    [tutorial.kicad_pcb]
2025-01-20 final YAML changes I didn't commit
    [tutorial.step]
2025-01-20 removed unneeded files
    [splitboard.kicad_pcb, splitboard.kicad_sch]
2025-01-30 added lots of footprints I doubt I'll need
    [CUI_DEVICES_SJ-43504-SMT-TR.step, CUI_SJ-43614-SMT-TR.step, EC11B-SW-Horiz-15K-blue.step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]
2025-01-31 get the right footprints finally
    [v2.kicad_pcb, v2.kicad_sch]
2025-01-31 started adding backlighting
    [v2.kicad_pcb, v2.kicad_sch]
2025-01-31 did some layout using a plugin
    [v2.kicad_pcb]
2025-01-31 schematic finished + some pcb
    [v2.kicad_pcb, v2.kicad_sch]
2025-02-01 I screwed up some layout
    [v2.kicad_pcb]
2025-02-01 layout fix started
    [v2.kicad_pcb]
2025-02-02 started moving some of the keys into place
    [v2.kicad_pcb, v2.kicad_sch]
2025-02-03 finished layout for all components
    [v2.kicad_pcb, v2.kicad_sch]
2025-02-03 added custom dual side hybrid diode footprint
    [v2.kicad_pcb, v2.kicad_sch]
2025-02-03 started running traces
    [v2.kicad_pcb, v2.kicad_sch]
2025-02-03 done for tonight, more trace routing
    [v2.kicad_pcb]
2025-02-05 redo some schematics, time to redo LEDs
    [v2.kicad_pcb, v2.kicad_sch]
2025-02-05 fix LED placement
    [v2.kicad_pcb]
2025-02-05 finished routing and make fill zones
    [v2.kicad_pcb, v2.kicad_sch]
2025-02-05 remove fill zones
    [v2.kicad_pcb]
2025-02-07 added qmk powered logo
    [v2.kicad_pcb]
2025-02-07 import and export 3d models
    [Cherry MX.STEP, EC11 Rotary Encoder Dode Switch-15mm .STEP, [low detail] Low Profile Cherry MX Red.step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]
2025-02-13 added qrcode and decals
    [v2.kicad_pcb]
2025-02-18 start v3 with nice!nano
    [v2.dxf, v2.kicad_pcb, v2.kicad_sch]
2025-02-18 started adding the nice!nano footprints
    [demo.dxf]
2025-02-19 redid footprints and layout for pcb
    [v2.kicad_pcb, v2.kicad_sch]
2025-02-19 start placing switches
    [switches.dxf, v2.kicad_pcb, v2.kicad_sch]
2025-02-19 grid sizing right and other fun stuff
    [v2.kicad_pcb]
2025-02-19 added all needed labels
    [v2.kicad_pcb, v2.kicad_sch]
2025-02-19 place keyswitches
    [v2.kicad_pcb]
2025-02-19 reversible nice!nano
    [v2.kicad_pcb, v2.kicad_sch]
2025-02-19 finish routing all traces
    [v2.kicad_pcb]
2025-02-19 added edge cuts and started cad again
    [KS33-low profile.step, switches_plate.dxf, v2.kicad_pcb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]
2025-02-20 redo pcb export
    [v3.step]
2025-02-20 fix lots of reversible error stuff
    [Gateron_ks33_hotswap_socket.step, v2.kicad_pcb]
2025-02-20 added branding
    [v2.kicad_pcb]
2025-02-20 added ground pads
    [v2.kicad_pcb]
2025-02-28 uhh nothing to pull so maybe an actual commit?
    [AdhesionSupport_MFP_1.5u.step.stl, AdhesionSupport_MFP_1u.step.stl, v2.kicad_pcb]
2025-03-09 update schematic files
    [v2.kicad_sch]
2025-03-09 add BOM to readme
2025-03-09 added total cost to BOM
2025-03-09 PCB cost
2025-03-10 Updated BOM with shipping costs
2025-03-10 Movethings into subdirectories
    [128x32-OLED.STEP, AdhesionSupport_MFP_1.5u.step.stl, AdhesionSupport_MFP_1u.step.stl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]
2025-03-10 added cad screenshots
2025-03-11 built firmware .uf2 files for production
    [Rev 3 part studio - Case.step, Rev 3 part studio - Plate.step]
